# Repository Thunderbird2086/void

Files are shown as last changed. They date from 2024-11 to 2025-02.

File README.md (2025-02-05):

# VOID
## An Ergonomic 3x5 Split Keyboard

The VOID keyboard is meticulously designed to offer an ergonomic typing experience with its compact 3x5 layout. It supports a variety of switch types, including CherryMX, Choc V1/V2, and a hybrid configuration.

Similar to the [uniCorne](https://github.com/Thunderbird2086/uniCorne), the VOID keyboard features controller compatibility, hardware handedness, and Nice!View integration. Additionally, for communication between each side in wired keyboards using PR2040/ProMicro, it uses a USB Type-C connector instead of TRRS to avoid short circuit issues that can damage MCUs.

The pinky column is slightly splayed while the others are column staggered. For wireless keyboards, the VOID has a power connector to the MCU and an onboard pogo pin connector to the charger board, which can be directly connected to a battery.

## Images
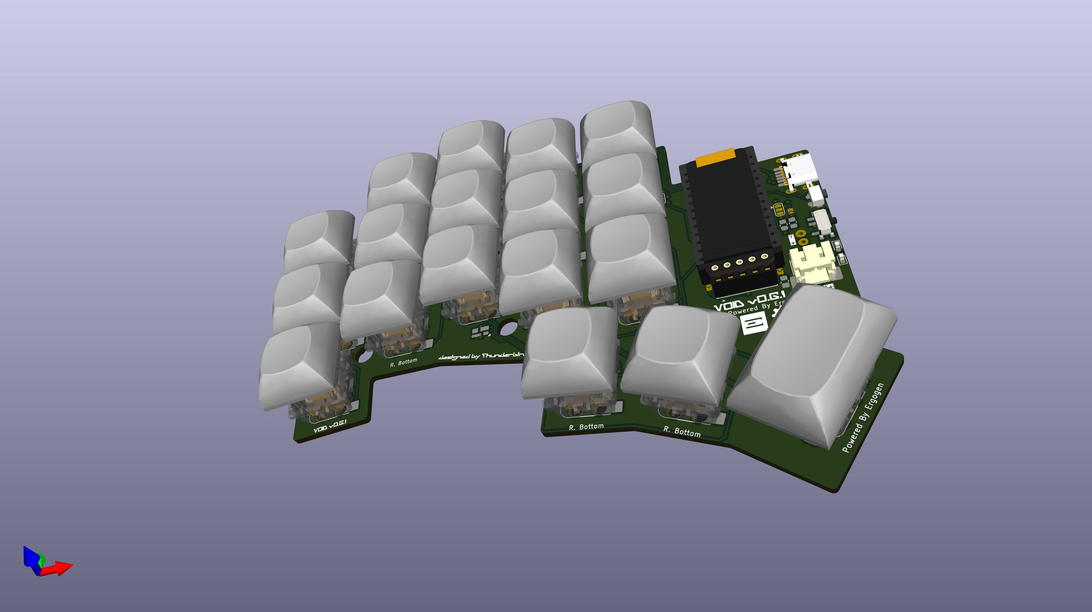
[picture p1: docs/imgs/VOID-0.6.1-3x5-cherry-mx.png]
CherryMX


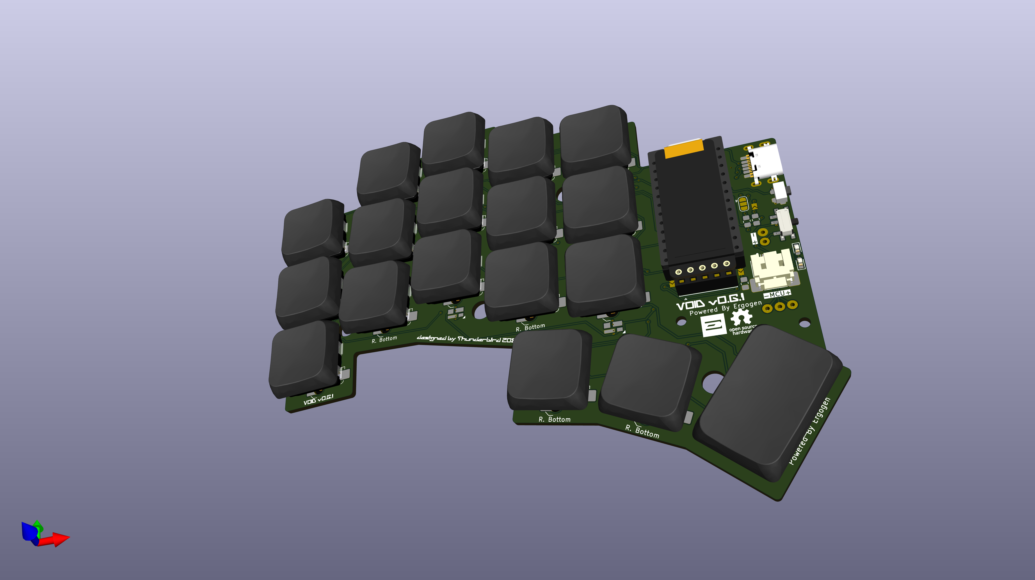
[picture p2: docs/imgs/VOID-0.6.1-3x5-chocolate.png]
Choc V1/V2


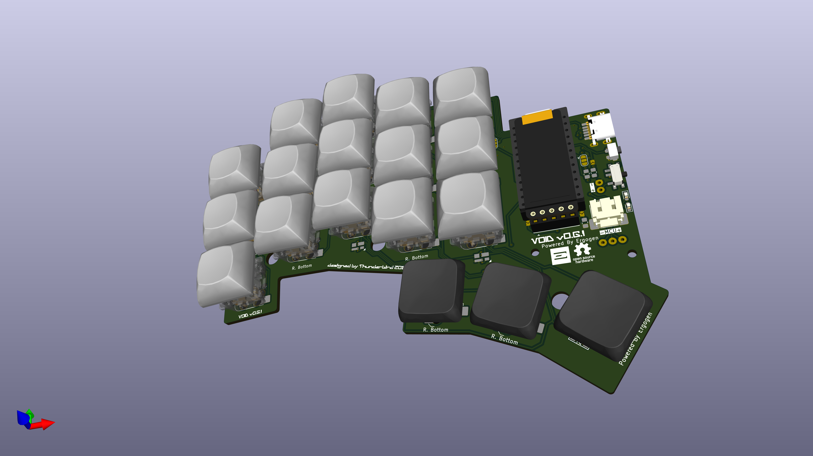
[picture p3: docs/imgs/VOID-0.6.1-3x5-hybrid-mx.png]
Hybrid


## Build guide
TODO

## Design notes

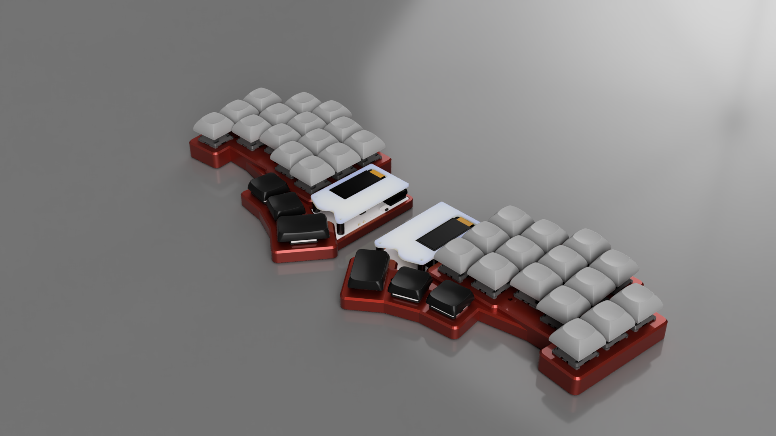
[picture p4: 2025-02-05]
docs/imgs/VOID-0.5.9-Hybrid-MX-case-Take01.PNG

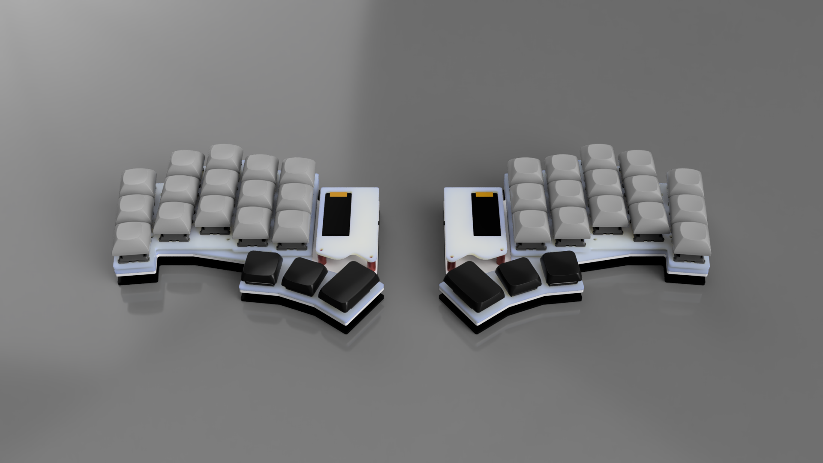
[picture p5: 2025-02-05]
docs/imgs/VOID_Hybrid_MX_Redered-take-02.png

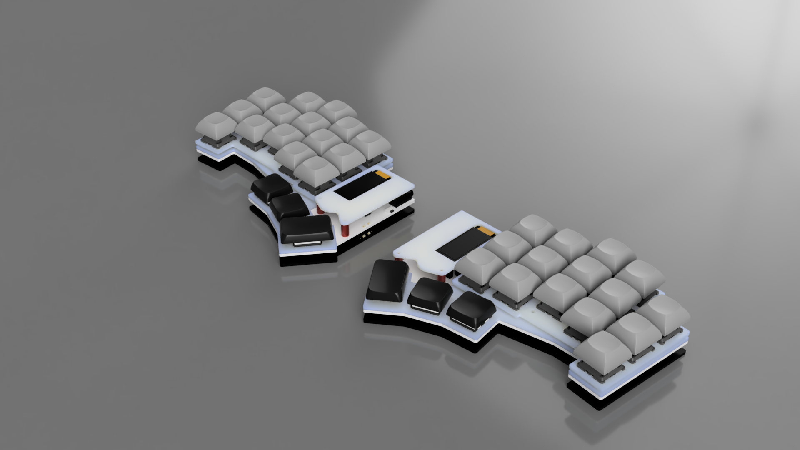
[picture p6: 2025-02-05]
docs/imgs/VOID_Hybrid_MX_Redered-take-01.png

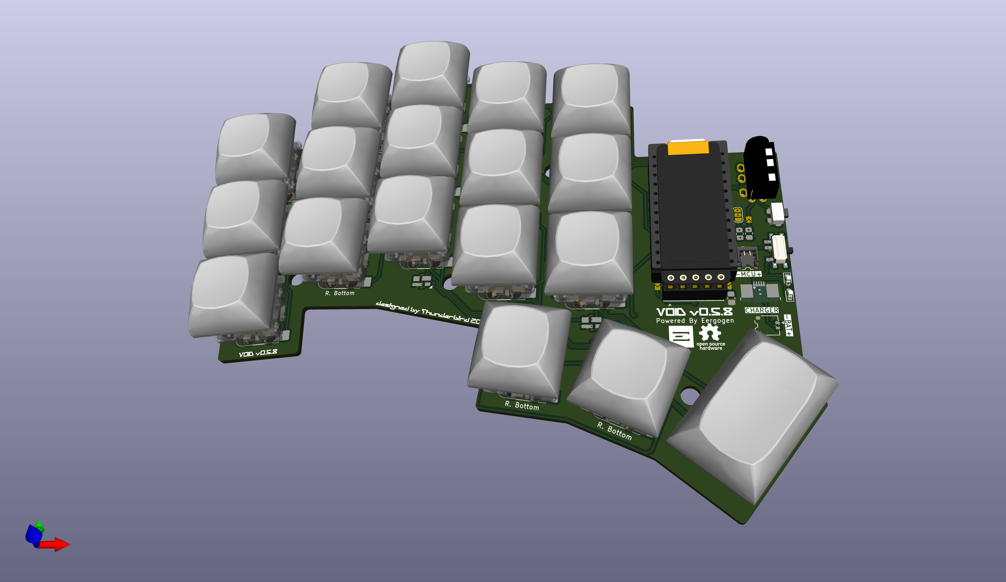
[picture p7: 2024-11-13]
docs/imgs/VOID-0.5.9-3x5-cherry-mx.png

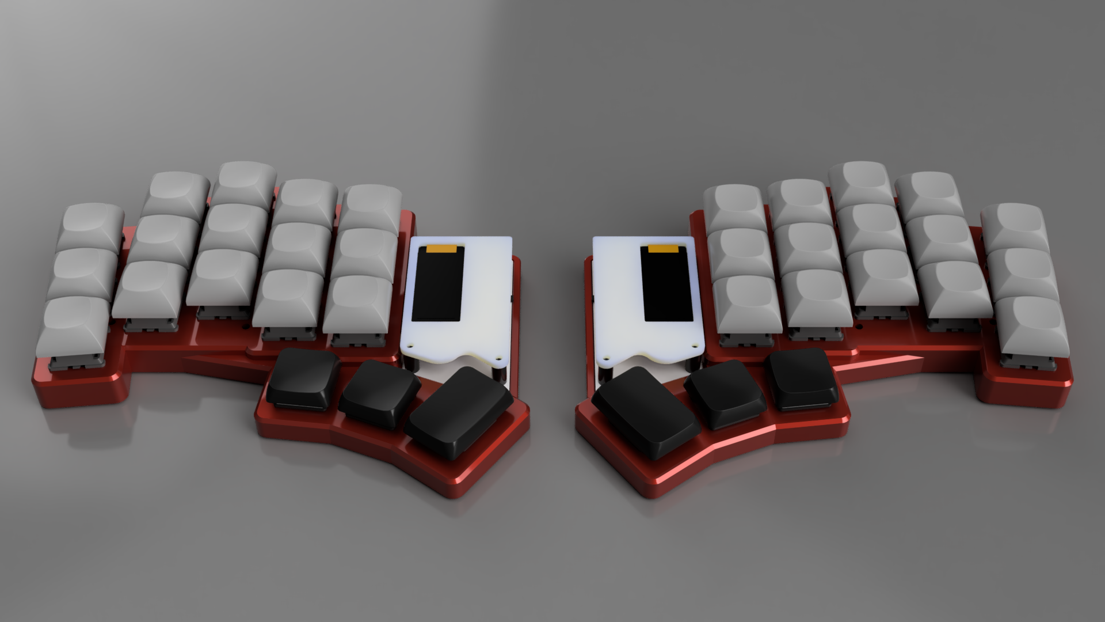
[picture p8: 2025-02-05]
docs/imgs/VOID-0.5.9-Hybrid-MX-case-Take02.png

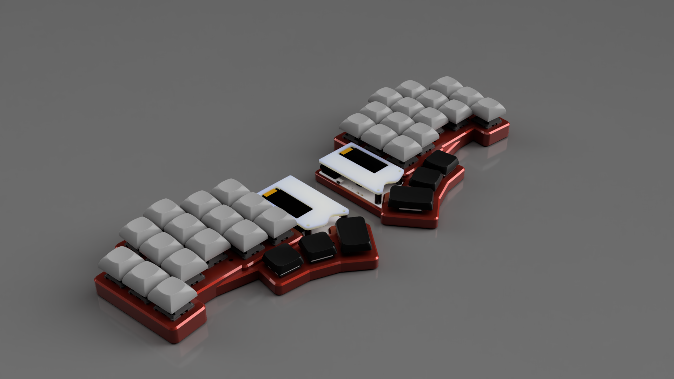
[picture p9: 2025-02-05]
docs/imgs/VOID-0.5.9-Hybrid-MX-case-Take03.png

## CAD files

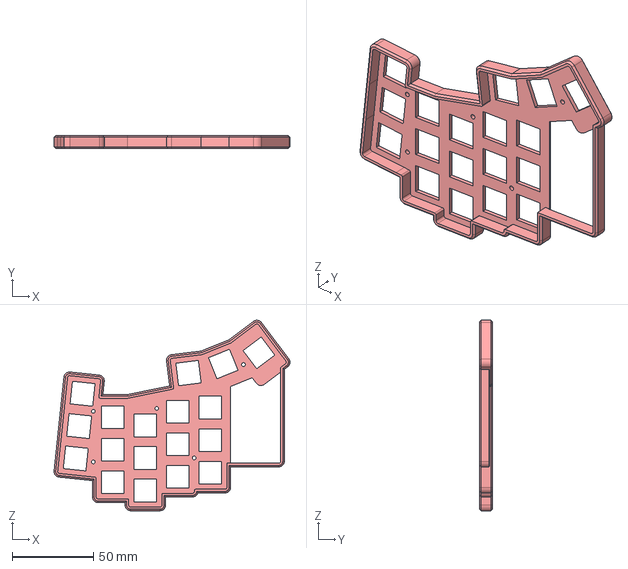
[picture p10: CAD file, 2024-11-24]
case/step/choc/void-choc-left.step
145.5 x 8.10 x 117.5 mm

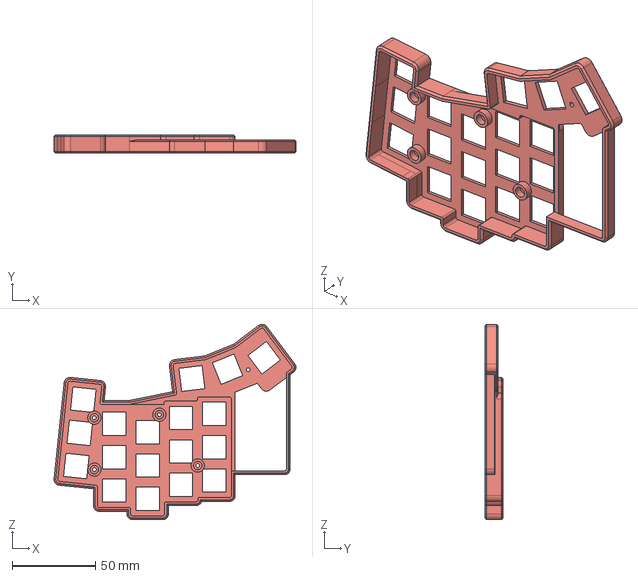
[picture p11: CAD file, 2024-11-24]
case/step/hybrid/void-hybrid-left.step
145.5 x 11.1 x 117.5 mm

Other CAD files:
case/step/mx/void-mx-left.step
case/step/choc/void-choc-right.step
case/step/hybrid/void-hybrid-right.step
case/step/mx/void-mx-right.step
case/stl/choc/void-choc-left.stl
case/stl/choc/void-choc-right.stl
case/stl/hybrid/void-hybrid-left.stl
case/stl/hybrid/void-hybrid-right.stl
case/stl/mx/void-mx-left.stl
case/stl/mx/void-mx-right.stl

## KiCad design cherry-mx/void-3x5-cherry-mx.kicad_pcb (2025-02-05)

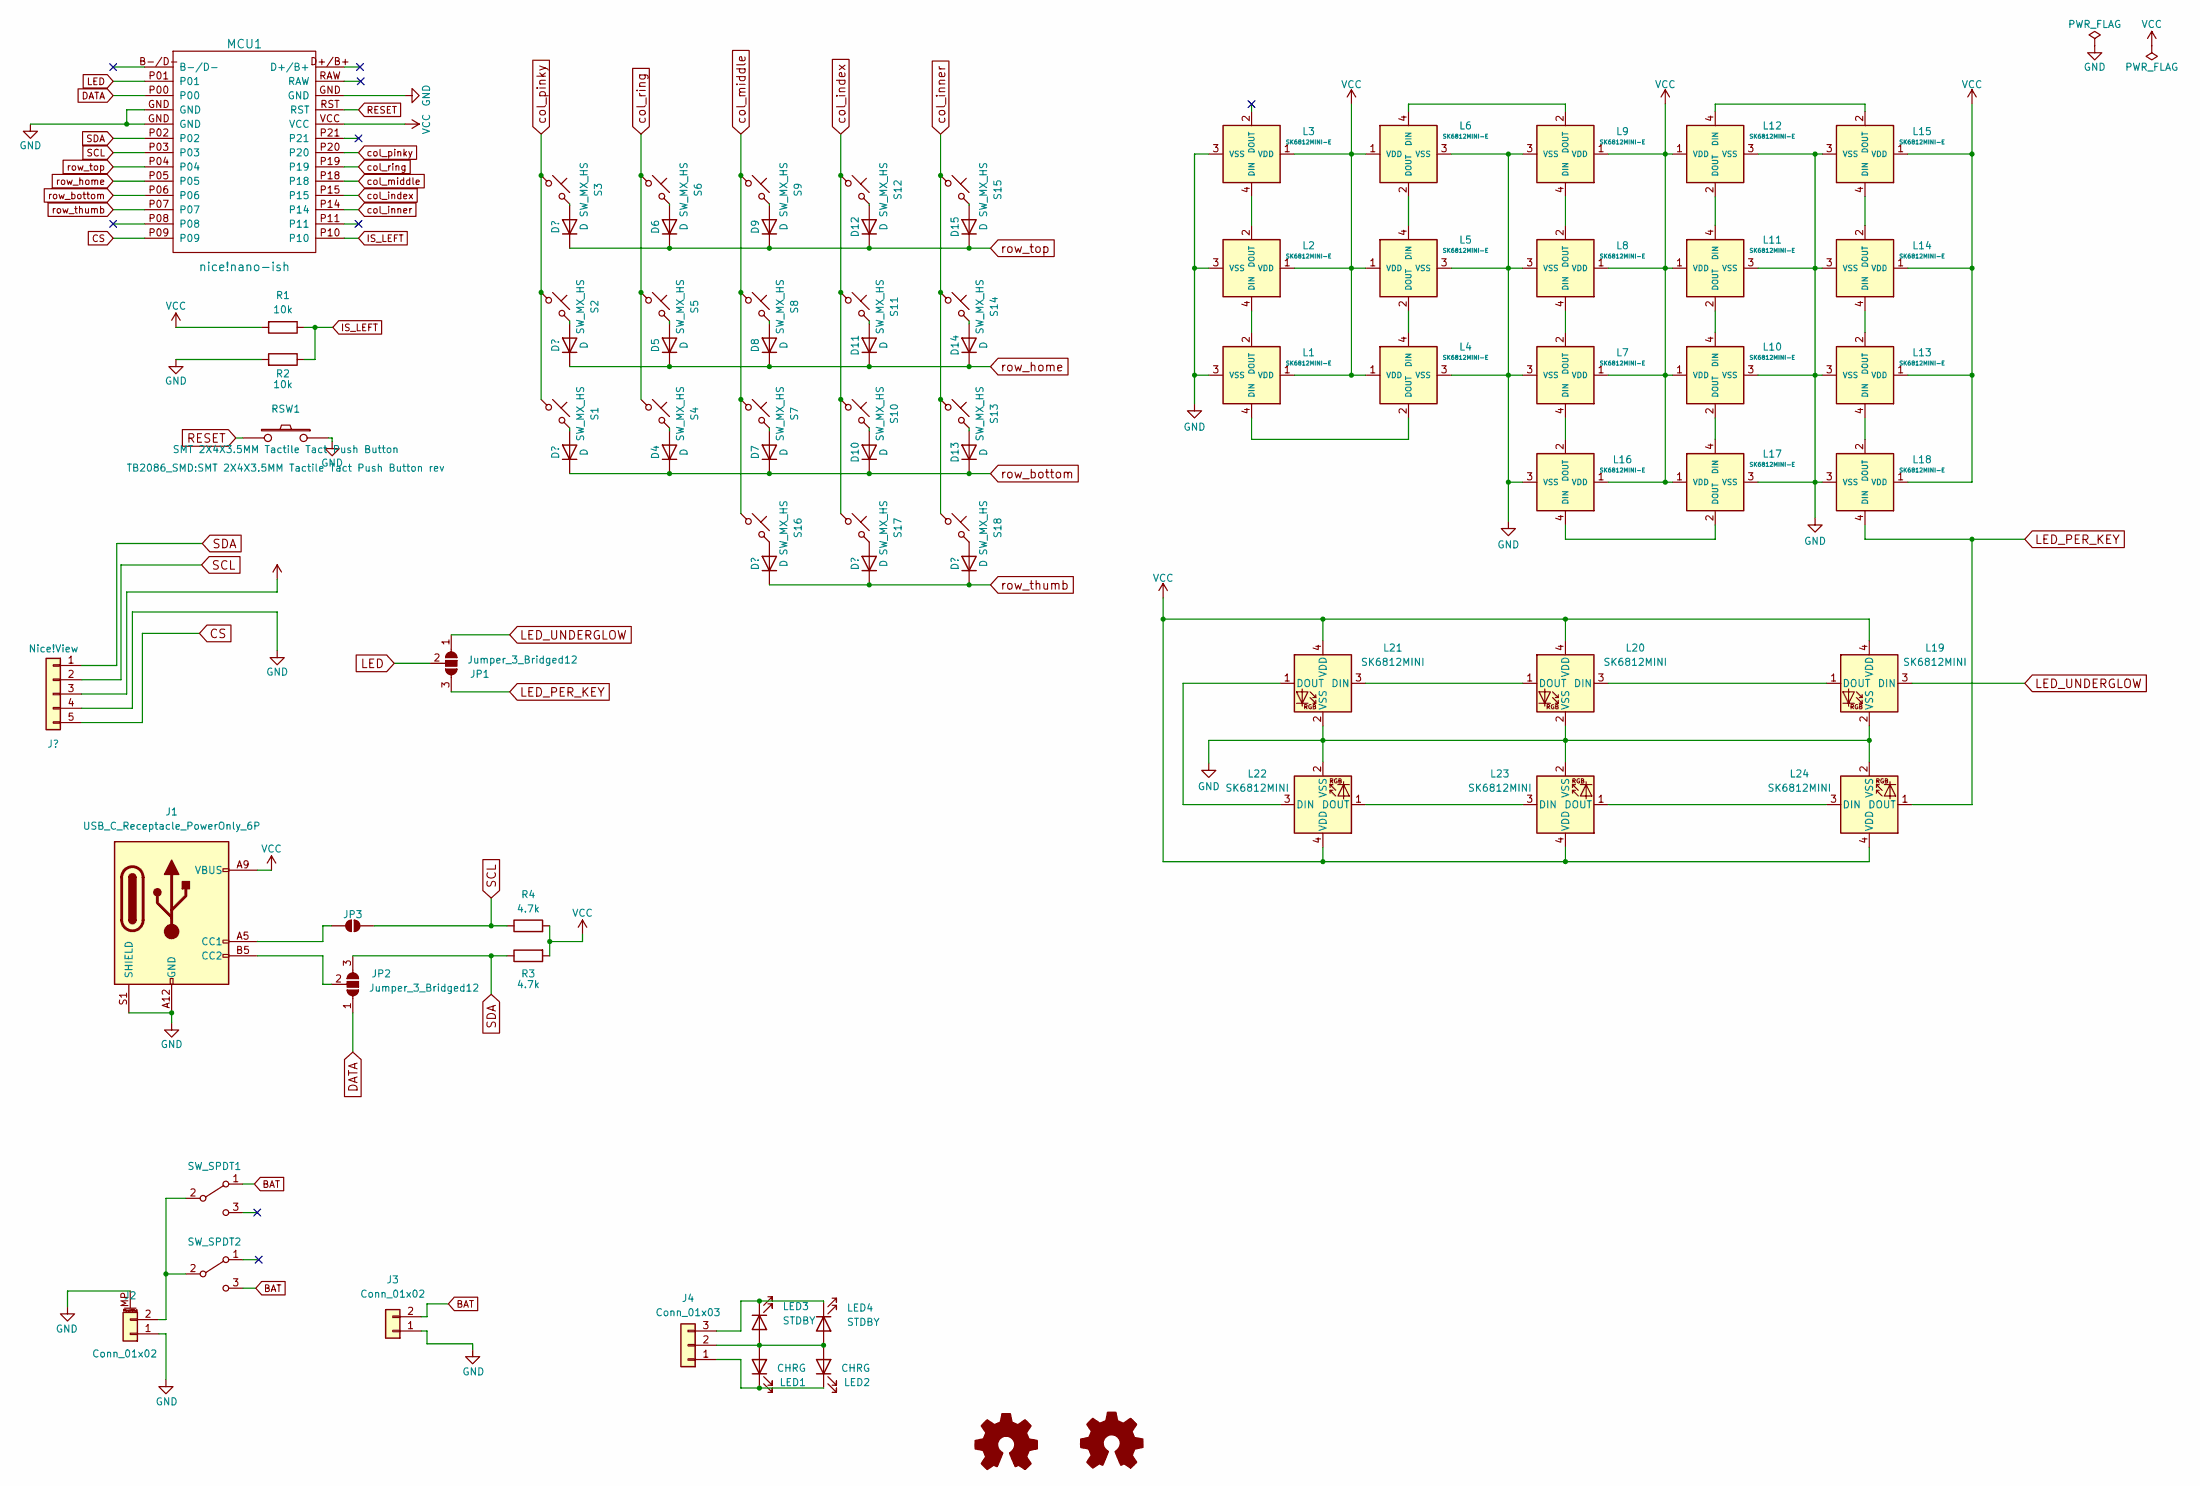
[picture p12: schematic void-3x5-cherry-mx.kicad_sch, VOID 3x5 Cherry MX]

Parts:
D1, D2, D3, D4, D5, D6, D7, D8, D9, D10, D11, D12, D13, D14, D15, D16, D17, D18: D; D3_SMD_rev
DISP1: Nice!View; Nice!View_rev
J1: USB_C_Receptacle_PowerOnly_6P; USB-20C-F-6C16_rev
J2: Conn_01x02; JST_PH_S2B-PH-SM4-TB_1x02-1MP_P2.00mm_Horizontal_rev
J3: Conn_01x02; Pogopin_1x02_P2.54mm
J4: Conn_01x03; Pogopin_1x03_P2.54mm
JP1, JP2: Jumper_3_Bridged12; SolderJumper-3_P1.3mm_Open_RoundedPad1.0x1.5mm_rev
JP3: SolderJumper-2_P1.3mm_Open_TrianglePad1.0x1.2mm_rev
L1, L2, L3, L4, L5, L6, L7, L8, L9, L10, L11, L12, L13, L14, L15, L16, L17, L18: SK6812MINI-E; LED_SK6812MINI-E_rev
L19, L20, L21, L22, L23, L24: SK6812MINI; LED_SK6812MINI_PLCC4_3.5x3.5mm_P1.75mm_rev_all
LED1, LED2: CHRG; LED_0603_1608Metric_Pad1.05x0.95mm_HandSolder
LED3, LED4: STDBY; LED_0603_1608Metric_Pad1.05x0.95mm_HandSolder
LOGO1: Logo_Open_ErgoGen; utility_ergogen_logo_rev
LOGO2: Logo_Open_Hardware_Small; OSHW-Logo_5.7x6mm_SilkScreen_rev
MCU1: nice!nano-ish; ProMicro-dn-rev-unrouted
R1, R2: 10k; R_0805_2012Metric_Pad1.20x1.40mm_HandSolder
R3, R4: 4.7k; R_0805_2012Metric_Pad1.20x1.40mm_HandSolder_rev
RSW1: SMT 2X4X3.5MM Tactile Tact Push Button; SMT 2X4X3.5MM Tactile Tact Push Button rev
S1, S2, S3, S4, S5, S6, S7, S8, S9, S10, S11, S12, S13, S14, S15, S16, S17: SW_MX_HS; SW_MX_HS_1u_reversible
S18: SW_MX_HS; SW_MX_HS_1.5u_reversible
SW_SPDT1: SW_SPDT1; SW_SPDT_PCM12
SW_SPDT2: SW_SPDT2; SW_SPDT_PCM12

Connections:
BAT: J3.2, SW_SPDT1.1 (A), SW_SPDT2.3 (C)
CS: DISP1.5, MCU1.P09
DATA: JP2.1 (A), MCU1.P00
GND: DISP1.4, J1.A12 (GND), J1.B12 (GND), J1.S1 (SHIELD), J2.1, J2.MP (MountPin), J3.1, L1.3 (VSS), L2.3 (VSS), L3.3 (VSS), L4.3 (VSS), L5.3 (VSS), L6.3 (VSS), L7.3 (VSS), L8.3 (VSS), L9.3 (VSS), L10.3 (VSS), L11.3 (VSS), L12.3 (VSS), L13.3 (VSS), L14.3 (VSS), L15.3 (VSS), L16.3 (VSS), L17.3 (VSS), L18.3 (VSS), L19.2 (VSS), L20.2 (VSS), L21.2 (VSS), L22.2 (VSS), L23.2 (VSS), L24.2 (VSS), MCU1.GND, R2.2, RSW1.1, RSW1.MP
IS_LEFT: MCU1.P10, R1.1, R2.1
LED: JP1.2 (C), MCU1.P01
LED_PER_KEY: JP1.3 (B), L18.4 (DIN), L24.1 (DOUT)
LED_UNDERGLOW: JP1.1 (A), L19.3 (DIN)
unnamed: D1.2 (A), S1.1
unnamed: D2.2 (A), S2.1
unnamed: D3.2 (A), S3.1
unnamed: D4.2 (A), S4.1
unnamed: D5.2 (A), S5.1
unnamed: D6.2 (A), S6.1
unnamed: D7.2 (A), S7.1
unnamed: D8.2 (A), S8.1
unnamed: D9.2 (A), S9.1
unnamed: D10.2 (A), S10.1
unnamed: D11.2 (A), S11.1
unnamed: D12.2 (A), S12.1
unnamed: D13.2 (A), S13.1
unnamed: D14.2 (A), S14.1
unnamed: D15.2 (A), S15.1
unnamed: D16.2 (A), S16.1
unnamed: D17.2 (A), S17.1
unnamed: D18.2 (A), S18.1
unnamed: J1.A5 (CC1), JP3.2 (B)
unnamed: J1.B5 (CC2), JP2.2 (C)
unnamed: J2.2, SW_SPDT1.2 (B), SW_SPDT2.2 (B)
unnamed: J4.1, LED1.1 (K), LED2.1 (K)
unnamed: J4.2, LED1.2 (A), LED2.2 (A), LED3.2 (A), LED4.2 (A)
unnamed: J4.3, LED3.1 (K), LED4.1 (K)
unnamed: L1.4 (DIN), L4.2 (DOUT)
unnamed: L1.2 (DOUT), L2.4 (DIN)
unnamed: L2.2 (DOUT), L3.4 (DIN)
unnamed: L4.4 (DIN), L5.2 (DOUT)
unnamed: L5.4 (DIN), L6.2 (DOUT)
unnamed: L6.4 (DIN), L9.2 (DOUT)
unnamed: L7.2 (DOUT), L8.4 (DIN)
unnamed: L8.2 (DOUT), L9.4 (DIN)
unnamed: L10.4 (DIN), L11.2 (DOUT)
unnamed: L10.2 (DOUT), L17.4 (DIN)
unnamed: L11.4 (DIN), L12.2 (DOUT)
unnamed: L12.4 (DIN), L15.2 (DOUT)
unnamed: L13.4 (DIN), L18.2 (DOUT)
unnamed: L13.2 (DOUT), L14.4 (DIN)
unnamed: L14.2 (DOUT), L15.4 (DIN)
unnamed: L16.4 (DIN), L17.2 (DOUT)
unnamed: L7.4 (DIN), L16.2 (DOUT)
unnamed: L19.1 (DOUT), L20.3 (DIN)
unnamed: L20.1 (DOUT), L21.3 (DIN)
unnamed: L21.1 (DOUT), L22.3 (DIN)
unnamed: L22.1 (DOUT), L23.3 (DIN)
unnamed: L23.1 (DOUT), L24.3 (DIN)
RESET: MCU1.RST, RSW1.2
SCL: DISP1.2, JP3.1 (A), MCU1.P03, R4.1
SDA: DISP1.1, JP2.3 (B), MCU1.P02, R3.1
VCC: DISP1.3, J1.A9 (VBUS), J1.B9 (VBUS), L1.1 (VDD), L2.1 (VDD), L3.1 (VDD), L4.1 (VDD), L5.1 (VDD), L6.1 (VDD), L7.1 (VDD), L8.1 (VDD), L9.1 (VDD), L10.1 (VDD), L11.1 (VDD), L12.1 (VDD), L13.1 (VDD), L14.1 (VDD), L15.1 (VDD), L16.1 (VDD), L17.1 (VDD), L18.1 (VDD), L19.4 (VDD), L20.4 (VDD), L21.4 (VDD), L22.4 (VDD), L23.4 (VDD), L24.4 (VDD), MCU1.VCC, R1.2, R3.2, R4.2
col_index: MCU1.P15, S10.2, S11.2, S12.2, S17.2
col_inner: MCU1.P14, S13.2, S14.2, S15.2, S18.2
col_middle: MCU1.P18, S7.2, S8.2, S9.2, S16.2
col_pinky: MCU1.P20, S1.2, S2.2, S3.2
col_ring: MCU1.P19, S4.2, S5.2, S6.2
row_bottom: D1.1 (K), D4.1 (K), D7.1 (K), D10.1 (K), D13.1 (K), MCU1.P06
row_home: D2.1 (K), D5.1 (K), D8.1 (K), D11.1 (K), D14.1 (K), MCU1.P05
row_thumb: D16.1 (K), D17.1 (K), D18.1 (K), MCU1.P07
row_top: D3.1 (K), D6.1 (K), D9.1 (K), D12.1 (K), D15.1 (K), MCU1.P04

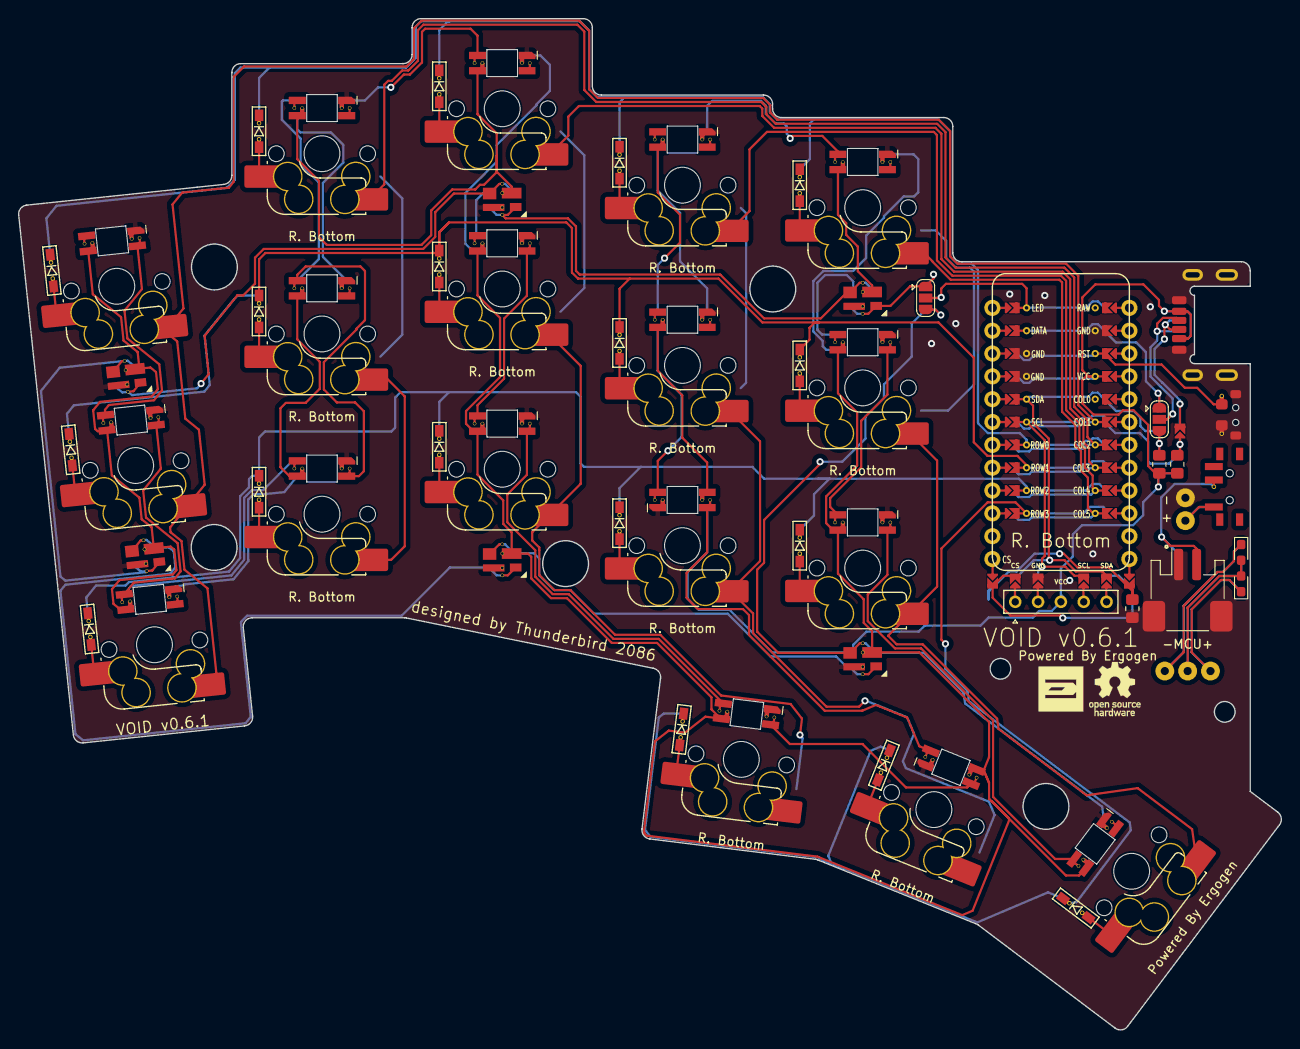
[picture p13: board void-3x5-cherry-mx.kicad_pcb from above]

Board: 2 copper layers, 140.5 x 112.5 mm, 82 parts (1 on the bottom side), 67 nets.

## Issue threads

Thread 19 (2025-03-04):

Wireless only version

Pacane, 2025-03-04:
Hi, I really like your design.

I was wondering if you had worked towards a simpler, wireless only version of this board. I say simpler, because I assume I could remove some of the unused components on the board.

I'd remove the usb-c port and probably the LEDs to save battery.

Thunderbird2086, 2025-03-06:
> I was wondering if you had worked towards a simpler, wireless only version of this board. I say simpler, because I assume I could remove some of the unused components on the board.

Yes, that's doable.    I tried to make it universal as much as possible so that people can choose what they want.

> I'd remove the usb-c port and probably the LEDs to save battery.

We can spin out different category of board as you suggested wireless only, which is simpler and easier.   As mentioned above, the concept of *universal*  increased the complexity.

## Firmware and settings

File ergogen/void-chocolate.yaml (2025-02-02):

meta:
  author: Allen Choi
  version: 0.6.1
  engine: 4.1.0
  project: VOID 3x5 Choc

units:
  # proxy spacing
  kx: U
  ky: U
  # padding
  px: kx+1
  py: ky+1
  corner: 1

points:
  zones:
    matrix:
      key: {padding: px, spread: px}
      columns:
        pinky: {key: {splay: 6, column_net: col_pinky}}
        ring: {key: {splay: -6, stagger: 12.5, column_net: col_ring}}
        middle: {key: {stagger: 5, column_net: col_middle}}
        index: {key: {stagger: -8.5, column_net: col_index}}
        inner: {key: {stagger: -2.5, shift: [0, 0], column_net: col_inner}}
      rows: &rows
        bottom: {row_net: row_bottom}
        home: {row_net: row_home}
        top: {row_net: row_top}
    cluster:
      key: {spread: 1kx}
      anchor: {ref: matrix_inner_bottom, shift: [-0.8kx, -ky], rotate: -7}
      columns:
        esc: {key: {shift: [2, -2], column_net: col_middle}}
        layer: {key: {splay: -15, shift: [6, -3.5], column_net: col_index}}
        space: {key: {width: 1.5px, splay: 75, shift: [1, -10], column_net: col_inner}}
      rows: {thumb: {row_net: row_thumb}}

outlines:
  raw: &raw
    - &rect_base
      what: rectangle
      bound: false
      joints: 2
    - <<: *rect_base
      where: [{ref: cluster_space_thumb}]
      size: [1.5px, py]
    - <<: *rect_base
      size: [px, py]
      where: [{ref: matrix_pinky_top, shift: [px, 0]}]
    - <<: *rect_base
      size: [px, py]
      where: [{ref: matrix_inner_top, shift: [-.5px, 0]}]
    - <<: *rect_base
      size: [px, py]
      where: true
      fillet: corner

  keys: &keys
    - what: rectangle
      where: true
      size: [kx-0.5, ky-0.5]

  switches: &switches
    - what: rectangle
      where: true
      asym: source
      size: 14

  mcu_body: &mcu_body
    - what: rectangle
      where: {ref: matrix_inner_top}
      size: [px, py]
    - what: rectangle
      where: {ref: matrix_inner_top, shift: [px, -1.8py]}
      size: [2.3px, 3py]
      fillet: corner
      joints: 2
      
  controller: # MCU
    - <<: *rect_base
      where: {ref: matrix_inner_top}
      size: [px, py]
      fillet: corner
    - <<: *rect_base
      where: {ref: matrix_index_top}
      size: [px, py]
      fillet: corner
    - mcu_body
    
  patch_thumb_layer:
    - <<: *rect_base
      where: {ref: matrix_inner_bottom, shift: [0, -.3py]}
      size: [px, 2py]
    - <<: *rect_base
      where: {ref: cluster_esc_thumb, shift: [0, 7]}
      size: [px, py]
    - <<: *rect_base
      where: {ref: cluster_esc_thumb, shift: [0, 0]}
      size: [px, py]
    - <<: *rect_base
      where: {ref: cluster_layer_thumb, shift: [0, 0]}
      size: [px, py]
    - <<: *rect_base
      where: {ref: cluster_space_thumb, shift: [0, 0]}
      size: [1.5px, py]
    - <<: *rect_base
      where: {ref: cluster_layer_thumb, shift: [0, .1py]}
      size: [px, py]
    - <<: *rect_base
      where: {ref: cluster_layer_thumb, shift: [.5px, .1py]}
      size: [px, py]
      fillet: corner

  patch_inner:
    - <<: *rect_base
      where: {ref: matrix_index_home, shift: [.5px, 0]}
      size: [px, py]
    - <<: *rect_base
      where: {ref: matrix_index_bottom, shift: [.5px, 0]}
      size: [px, py]
      fillet: corner
      
  patch_ring:  # filling the gap between ring bottom and board
    - what: rectangle
      where: {ref: matrix_pinky_bottom}
      size: [px, py]
    - what: rectangle
      where: {ref: matrix_pinky_home, shift: [2, -2]}
      size: [px, 1.5py]
    - what: rectangle
      where: {ref: matrix_ring_bottom, shift: [0, -1.5]}
      size: [px, py]
    - what: rectangle
      where: {ref: cluster_esc_thumb}
      size: [px, py]
    - what: polygon
      points:
        - ref: cluster_esc_thumb
          shift: [0, 8]
        - ref: matrix_index_bottom
          shift: [7, -0.5py]
        - ref: matrix_middle_bottom
          shift: [7, -0.1py]
        - ref: matrix_ring_bottom
          shift: [-8, -8]
      fillet: corner
      joints: 2

  top_outline:
    - "raw"
    - "+patch_ring"
    - "+patch_inner"
    - "+patch_thumb_layer"
  
  base_outline:
    - "top_outline"
    - "+controller"
  
  screw_holes:
    top_left: &screw_base
      what: circle
      where: [{ref: matrix_pinky_top, shift: [.5kx+1.5, 1]}]
      radius: 1.15
    bottom_left: {<<: *screw_base, where: [{ref: matrix_ring_bottom, shift: [-12, -3.7]}]}
    top_right: {<<: *screw_base, where: [{ref: matrix_inner_home, shift: [-10, 11]}]}
    palm: {<<: *screw_base, where: [{ref: matrix_index_bottom, shift: [-13, -2]}]}
    thumb: {<<: *screw_base, where: [{ref: cluster_layer_thumb, shift: [0.6kx, 5]}]}

  lcd_screw_holes:
    left: &lcd_screw_base
      what: circle
      where: [{ref: cluster_layer_thumb, shift: [1, 17.3]}]
      radius: 1.15
    right: {<<: *lcd_screw_base, where: [{ref: cluster_space_thumb, shift: [20.4, 2.4]}]}
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

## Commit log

2024-11-13 0.5.8 (#1)
    * initial commit
    * bottom plate
    * rename
    * added hybrid
    * added choc
    * choc
    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
    [bottom-plate.kicad_pcb, top-plate.kicad_pcb, void-3x5-cherry-mx.kicad_pcb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]
2024-11-17 Choc (#4)
    * updated mcu footprint for choc
    * added holes for oled window
    * hybrid top plate
    * added hybrid top plate
    [top-plate-hybrid.kicad_pcb, void-3x5-cherry-mx.kicad_pcb, void-3x5-chocolate.kicad_pcb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]
2024-11-17 workflow for plates (#5)
2024-11-17 Fix workflow (#6)
    * fix workflow for plates
    * minor fix
    [bottom-plate.kicad_sch, top-plate-hybrid.kicad_sch, top-plate.kicad_sch]
2024-11-18 Mcu cover (#7)
    * more plates
    * updated workflow
    * mcu cover
    * small change
    [bottom-plate-with-mcu-cover.kicad_pcb, bottom-plate-with-mcu-cover.kicad_sch, bottom-plate.kicad_pcb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]
2024-11-18 amended hybrid top (#8)
    [top-plate-hybrid.kicad_pcb]
2024-11-20 fixed mcu window size (#9)
    [mcu-cover.kicad_pcb, void-3x5-chocolate.kicad_pcb]
2024-11-24 added step/stl for cases (#10)
    [bottom-plate-with-mcu-cover.kicad_pcb, mcu-cover.kicad_pcb, void-choc-left.stl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]
2024-11-24 added missing step files (#11)
    [void-choc-left.step, void-choc-right.step, void-hybrid-left.step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]
2024-11-26 fixed bridge for hybrid-mx (#13)
    [void-3x5-hybrid-mx.kicad_pcb, void-3x5-hybrid-mx.kicad_sch]
2025-02-01 Changed TRRS to USB-C connector (#14)
    * usb-c mod for hybrid
    * updated
    - submodule
    - ergogen yaml
    - schematic and pcb
    * updated cherry-mx
    usb-c for communication between left and right hand sides
    * updated choc
    * updated choc
    * fixed corner
    * void-choc
    * ergogen
    - bottom plate
    - charger plate
    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
    [bottom-plate.kicad_pcb, top-plate-hybrid.kicad_pcb, top-plate.kicad_pcb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]
2025-02-02 Small tweaks (#15)
    * updated submodule
    * small touches
    * changed version
    [void-3x5-cherry-mx.kicad_pcb, void-3x5-chocolate.kicad_pcb, void-3x5-hybrid-mx.kicad_pcb]
2025-02-02 Quick fixes (#16)
    * fix version
    * updated PCB
    [void-3x5-cherry-mx.kicad_pcb, void-3x5-cherry-mx.kicad_sch, void-3x5-chocolate.kicad_pcb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]
2025-02-02 Fix ergogen (#17)
    * refreshed submodule
    * updated ergogen files
    * updated kicad data
    [void-3x5-cherry-mx.kicad_pcb, void-3x5-cherry-mx.kicad_sch, void-3x5-chocolate.kicad_pcb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]
2025-02-05 Readme (#18)
    * updated readme
    * fixed broken link to uniCorne
    [void-3x5-cherry-mx.kicad_pcb]
